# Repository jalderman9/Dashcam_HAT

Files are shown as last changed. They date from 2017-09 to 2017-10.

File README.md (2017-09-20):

# Dashcam HAT

This repository contains the Eagle PCB design files for a board that
attaches to an ASUS Tinkerboard and provides:
 - Regulated 5V power from OBD-II 12V supply
 - Power management via Attiny
 - OBD-II interface (CAN and ISO9141)
 - 3 axis accelerometer
 - magnetometer
 - GPS

PCB top view:

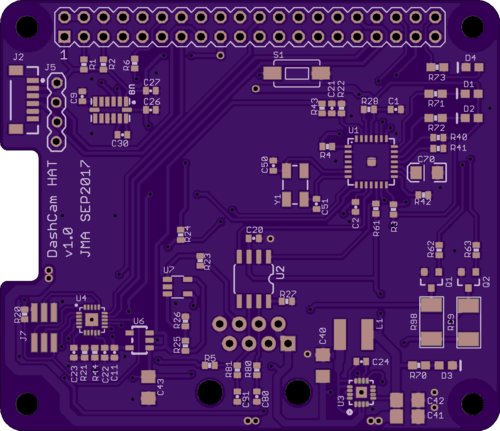
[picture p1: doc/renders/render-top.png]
 

PCB bottom view:

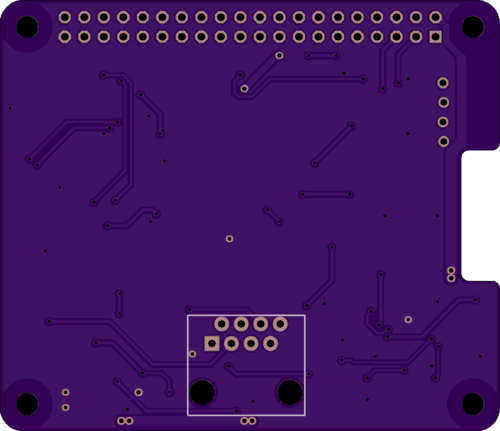
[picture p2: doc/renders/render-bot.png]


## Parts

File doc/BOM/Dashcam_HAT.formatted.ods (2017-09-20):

Qty | Value | Device | Parts | Description | DIGIKEY_PN | MANUFACTURER | MFG_PN
7 | 0.1uF | CAP0402-CAP | C20, C21, C22, C23, C24, C26, C27 | Capacitor | 1276-1001-1-ND | Samsung | CL05B104KO5NNNC
1 | 0.22uF | CAP0402-CAP | C30 | Capacitor | 490-5418-1-ND | Murata | GRM155R71C224KA12D
2 | 27pF | CAP0402-CAP | C50, C51 | Capacitor | 1276-1153-1-ND | Samsung | CL05C270JB5NNNC
3 | 1uF | CAP0402-CAP | C1, C2, C11 | Capacitor | 490-3890-1-ND | Murata | GRM155R61A105KE15D
4 | 10uF | CAP1206 | C40, C41, C42, C43 | Capacitor | 1276-6767-1-ND | Samsung | CL31B106KBHNNNE
1 | 10uF ESR<=5 | CAP_POL1206 | C70 | Capacitor Polarized | 478-8237-1-ND | AVX Corporation | F931C106MAA
1 | 4.7uF | CAP0402-CAP | C9 | Capacitor | 490-5915-1-ND | Murata | GRM155R60J475ME47D
2 | 560pF | CAP0402-CAP | C80, C81 | Capacitor | 1276-1577-1-ND | Samsung | CL05B561KB5NNNC
4 | 1k | RESISTOR0402-RES | R6, R61, R62, R63 | Resistor | 311-1.0KJRCT-ND | Yageo | RC0402JR-071KL
5 | 3.9K | RESISTOR0402-RES | R1, R2, R3, R4, R5 | Resistor | 311-3.9KJRCT-ND | Yageo | RC0402JR-073K9L
9 | 10k | RESISTOR0402-RES | R20, R21, R22, R23, R24, R25, R26, R27, R28 | Resistor | 311-10KJRCT-ND | Yageo | RC0402JR-0710KL
5 | 62K | RESISTOR0402-RES | R40, R41, R42, R43, R44 | Resistor | 311-62.0KLRCT-ND | Yageo | RC0402FR-0762KL
2 | 100 | RESISTOR0402-RES | R80, R81 | Resistor | 311-100JRCT-ND | Yageo | RC0402JR-07100RL
4 | 470 | RESISTOR0603-RES | R70, R71, R72, R73 | Resistor | 311-470JRCT-ND | Yageo | RC0402JR-07470RL
2 | 510 0.5W | R-US_2010 | R98, R99 | Resistor, US Symbol | RHM510BGCT-ND | Rohm Semiconductor | MCR50JZHJ511
1 | 16MHz | CRYSTAL5X3 | Y1 | Crystals | 535-9122-1-ND | Abracon LLC | ABM3B-16.000MHZ-B2-T
1 | BLU | LED0603 | D4 | Surface mount LED | 160-1646-1-ND | Lite-On Inc | LTST-C190TBKT
1 | GRN | LED0603 | D1 | Surface mount LED | 160-1183-1-ND | Lite-On Inc | LTST-C190GKT
1 | ORG | LED0603 | D2 | Surface mount LED | 160-1434-1-ND | Lite-On Inc | LTST-C190KFKT
1 | RED | LED0603 | D3 | Surface mount LED | 160-1436-1-ND | Lite-On Inc | LTST-C190KRKT
1 | ATTINY441/841VQFN20 | ATTINY441/841VQFN20 | U4 | ATtiny441/841 | ATTINY841-MMH-ND | Atmel | ATTINY841-MMH
2 | MMBT2222 | TRANSISTOR_NPNSOT23-3 | Q1, Q2 | Transistor NPN | MMBT2222ALT1GOSCT-ND | ON Semiconductor | MMBT2222ALT1G
1 | NR5040T4R7N | NR5040T4R7N | L1 | Taiyo Yuden Inductor | 587-2373-1-ND | Taiyo Yuden | 587-2373-1-ND
1 | Mom | SWITCH-MOMENTARY-2-SMD-1101NE | S1 |  | P13597SCT-ND | Panasonic | EVQ-PNF04M
1 | STN1110 | SCANTOOL | U1 | STN1110 - Multiprotocol OBD II to UART Interpreter, QFN Package |  | Scantool | STN1110
1 | TL331 | TL331 | U7 | Single differential comparator | 296-10168-1-ND | Texas Instruments | TL331IDBVR
1 | TS30011 | TS30011 | U3 | Semtech High Efficiency 1A/2A/3A Current-Mode | TS30013-M050QFNRCT-ND | Semtech | TS30013-M050QFNR
1 | 3V3 | TC1XXXSOT23-5 | U6 | TC1014/TC1015/TC1185 voltage regulator | AP2204K-3.3TRG1DICT-ND | Diodes Inc | AP2204K-3.3TRG1
1 | LSM303DLHC | LSM303DLHC | U8 | 3-Axis I2C Accelerometer and 3-Axis Magnetometer | 497-11918-1-ND | STMicroelectronics | LSM303DLHCTR
1 | MCP2551 | MCP2551-I/SN | U2 | CAN Driver | MCP2551T-E/SNCT-ND | Microchip Technology | MCP2551T-E/SN
1 | M4 | M4 | J5 | 4 pin 0.1 pitch header
1 | 6_PIN_SMD | 6_PIN_PDISMD | J7 | 6 pin PDI programming header | 609-3693-1-ND | Amphenol FCI | 20021121-00006C4LF
1 | PIN20X2 | PIN20X2 | J3 |  | SAM9315-ND | Samtec Inc | ESQ-120-23-T-D
1 | JST_VERTICAL | JST_VERTICAL | J2 |  | 455-1792-1-ND | JST | BM06B-SRSS-TB(LF)(SN)
1 | RJ45-8PTH | RJ45-8PTH | J1 | RJ45 Jack | 609-1046-ND | Amphenol FCI | 54602-908LF

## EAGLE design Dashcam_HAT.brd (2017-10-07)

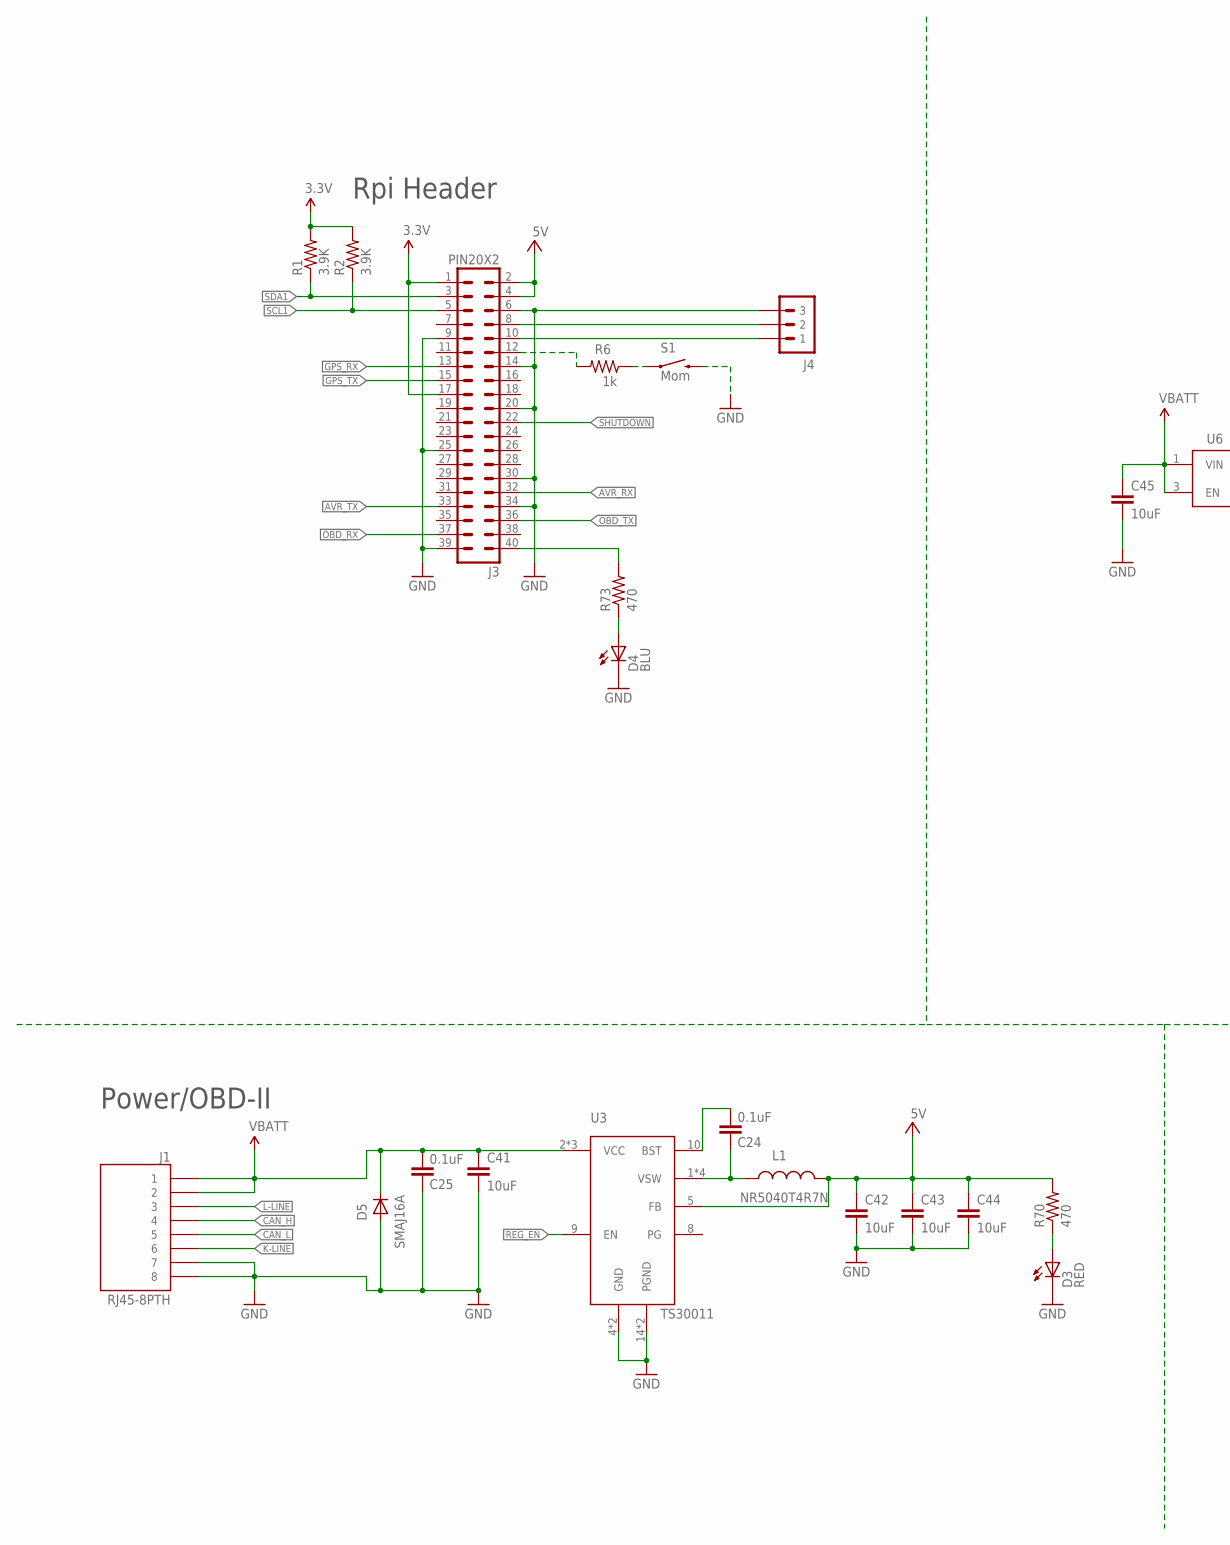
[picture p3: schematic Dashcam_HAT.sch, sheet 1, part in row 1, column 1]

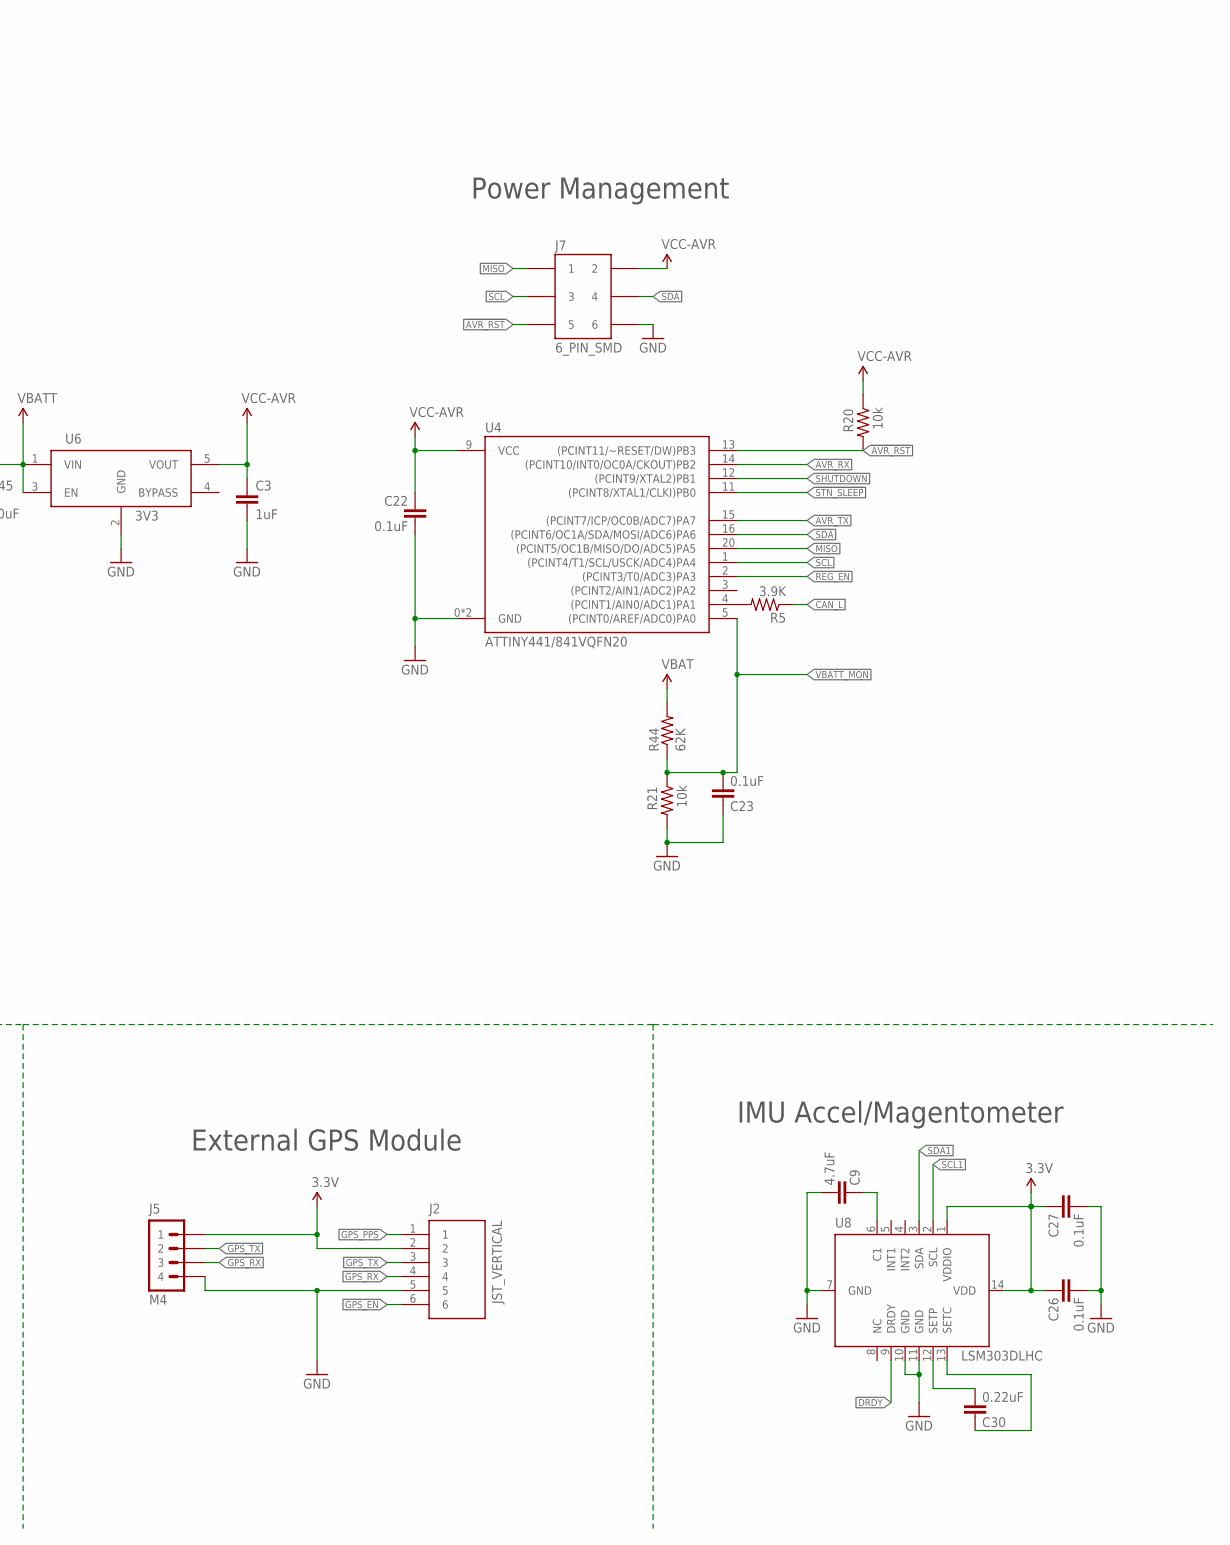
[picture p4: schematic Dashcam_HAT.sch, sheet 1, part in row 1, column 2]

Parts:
C3: 1uF; 0402-CAP; MFG_PN GRM155R61A105KE15D; DIGIKEY_PN 490-3890-1-ND
C9: 4.7uF; 0402-CAP; MFG_PN GRM155R60J475ME47D; DIGIKEY_PN 490-5915-1-ND
C22, C23, C24, C25, C26, C27: 0.1uF; 0402-CAP; MFG_PN CL05B104KO5NNNC; DIGIKEY_PN 1276-1001-1-ND
C30: 0.22uF; 0402-CAP; MFG_PN GRM155R71C224KA12D; DIGIKEY_PN 490-5418-1-ND
C41, C42, C43, C44, C45: 10uF; 1206; MFG_PN CL31B106KBHNNNE; DIGIKEY_PN 1276-6767-1-ND
D3: RED; LED_0603; MFG_PN LTST-C190KRKT; DIGIKEY_PN 160-1436-1-ND
D4: BLU; LED_0603; MFG_PN LTST-C190TBKT; DIGIKEY_PN 160-1646-1-ND
D5: SMAJ16A; SMA; MFG_PN SMAJ16A; DIGIKEY_PN SMAJ16ALFCT-ND
J1: RJ45-8PTH; RJ45-8; MFG_PN 54602-908LF; DIGIKEY_PN 609-1046-ND
J2: JST_VERTICAL; JST-6-SMD-VERT-1.0MM; MFG_PN BM06B-SRSS-TB(LF)(SN); DIGIKEY_PN 455-1792-1-ND
J3: PIN20X2; PIN_20X2; MFG_PN ESQ-120-23-T-D; DIGIKEY_PN SAM9315-ND
J4: M30.1"_LOCK; M3X1_LOCK
J5: M4; M4X1_LOCK
J7: 6_PIN_SMD; M3X2_SMD; MFG_PN 20021121-00006C4LF; DIGIKEY_PN 609-3693-1-ND
L1: NR5040T4R7N; NR5040; MFG_PN 587-2373-1-ND; DIGIKEY_PN 587-2373-1-ND
R1, R2, R5: 3.9K; 0402-RES; MFG_PN RC0402JR-073K9L; DIGIKEY_PN 311-3.9KJRCT-ND
R6: 1k; 0402-RES; MFG_PN RC0402JR-071KL; DIGIKEY_PN 311-1.0KJRCT-ND
R20, R21: 10k; 0402-RES; MFG_PN RC0402JR-0710KL; DIGIKEY_PN 311-10KJRCT-ND
R44: 62K; 0402-RES; MFG_PN RC0402FR-0762KL; DIGIKEY_PN 311-62.0KLRCT-ND
R70, R73: 470; 0603-RES; MFG_PN RC0402JR-07470RL; DIGIKEY_PN 311-470JRCT-ND
S1: Mom; TACTILE-SWITCH-1101NE; MFG_PN EVQ-PNF04M; DIGIKEY_PN P13597SCT-ND
U3: TS30011; QFN-16; MFG_PN TS30013-M050QFNR; DIGIKEY_PN TS30013-M050QFNRCT-ND
U4: ATTINY441/841VQFN20; QFN20_0.45MM; MFG_PN ATTINY841-MMH; DIGIKEY_PN ATTINY841-MMH-ND
U6: 3V3; SOT23-5; MFG_PN AP2204K-3.3TRG1; DIGIKEY_PN AP2204K-3.3TRG1DICT-ND
U8: LSM303DLHC; LGA14; MFG_PN LSM303DLHCTR; DIGIKEY_PN 497-11918-1-ND

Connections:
3.3V: C26.1, C27.1, J2.2, J3.1, J3.17, J5.1, R1.2, R2.2, U8.1 (VDDIO), U8.14 (VDD); also elsewhere on the board
5V: C42.1, C43.1, C44.1, J3.2, J3.4, L1.P$2 (2), R70.2, U3.5 (FB); also elsewhere on the board
!AVR_RST: J7.P$5 (5), R20.2, U4.13 ((PCINT11/~RESET/DW)PB3)
!STN_SLEEP: U4.11 ((PCINT8/XTAL1/CLKI)PB0); also elsewhere on the board
AVR_RX: J3.32, U4.14 ((PCINT10/INT0/OC0A/CKOUT)PB2)
AVR_TX: J3.33, U4.15 ((PCINT7/ICP/OC0B/ADC7)PA7)
BST: C24.2, U3.10 (BST)
CAN_H: J1.4; also elsewhere on the board
CAN_L: J1.5, R5.1; also elsewhere on the board
DRDY: U8.9 (DRDY)
GND: C3.2, C9.2, C22.2, C23.1, C25.1, C26.2, C27.2, C41.2, C42.2, C43.2, C44.2, C45.2, D3.C, D4.C, D5.A, J1.7, J1.8, J2.5, J3.6, J3.9, J3.14, J3.20, J3.25, J3.30, J3.34, J3.39, J4.3, J5.4, J7.P$6 (6), R21.2, S1.P$2 (2), U3.4 (GND), U3.14 (PGND), U3.15 (PGND), U3.EXP (GND), U4.0 (GND), U4.8 (GND), U6.2 (GND), U8.7 (GND), U8.10 (GND), U8.11 (GND); also elsewhere on the board
GPS_EN: J2.6
GPS_PPS: J2.1
GPS_RX: J2.4, J3.13, J5.3
GPS_TX: J2.3, J3.15, J5.2
K-LINE: J1.6; also elsewhere on the board
L-LINE: J1.3; also elsewhere on the board
MISO: J7.P$1 (1), U4.20 ((PCINT5/OC1B/MISO/DO/ADC5)PA5)
unnamed: C9.1, U8.6 (C1)
unnamed: R5.2, U4.4 ((PCINT1/AIN0/ADC1)PA1)
unnamed: D3.A, R70.1
unnamed: D4.A, R73.1
unnamed: C30.2, U8.12 (SETP)
unnamed: C30.1, U8.13 (SETC)
unnamed: J3.12, R6.2
unnamed: R6.1, S1.P$1 (1)
OBD_RX: J3.37; also elsewhere on the board
OBD_TX: J3.36; also elsewhere on the board
REG_EN: U3.9 (EN), U4.2 ((PCINT3/T0/ADC3)PA3)
SCL: J7.P$3 (3), U4.1 ((PCINT4/T1/SCL/USCK/ADC4)PA4)
SCL1: J3.5, R2.1, U8.2 (SCL)
SDA: J7.P$4 (4), U4.16 ((PCINT6/OC1A/SDA/MOSI/ADC6)PA6)
SDA1: J3.3, R1.1, U8.3 (SDA)
SHUTDOWN: J3.22, U4.12 ((PCINT9/XTAL2)PB1)
UART1_RX: J3.10, J4.1
UART1_TX: J3.8, J4.2
USER_LED: J3.40, R73.2
VBATT: C25.2, C41.1, C45.1, D5.K (C), J1.1, J1.2, R44.2, U3.2 (VCC), U3.3 (VCC), U3.11 (VCC), U6.1 (VIN), U6.3 (EN); also elsewhere on the board
VBATT_MON: C23.2, R21.1, R44.1, U4.5 ((PCINT0/AREF/ADC0)PA0)
VCC-AVR: C3.1, C22.1, J7.P$2 (2), R20.1, U4.9 (VCC), U6.5 (VOUT)
VSW: C24.1, L1.P$1 (1), U3.1 (VSW), U3.12 (VSW), U3.13 (VSW), U3.16 (VSW)

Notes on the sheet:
External GPS Module
Rpi Header
IMU Accel/Magentometer
Power/OBD-II
Power Management

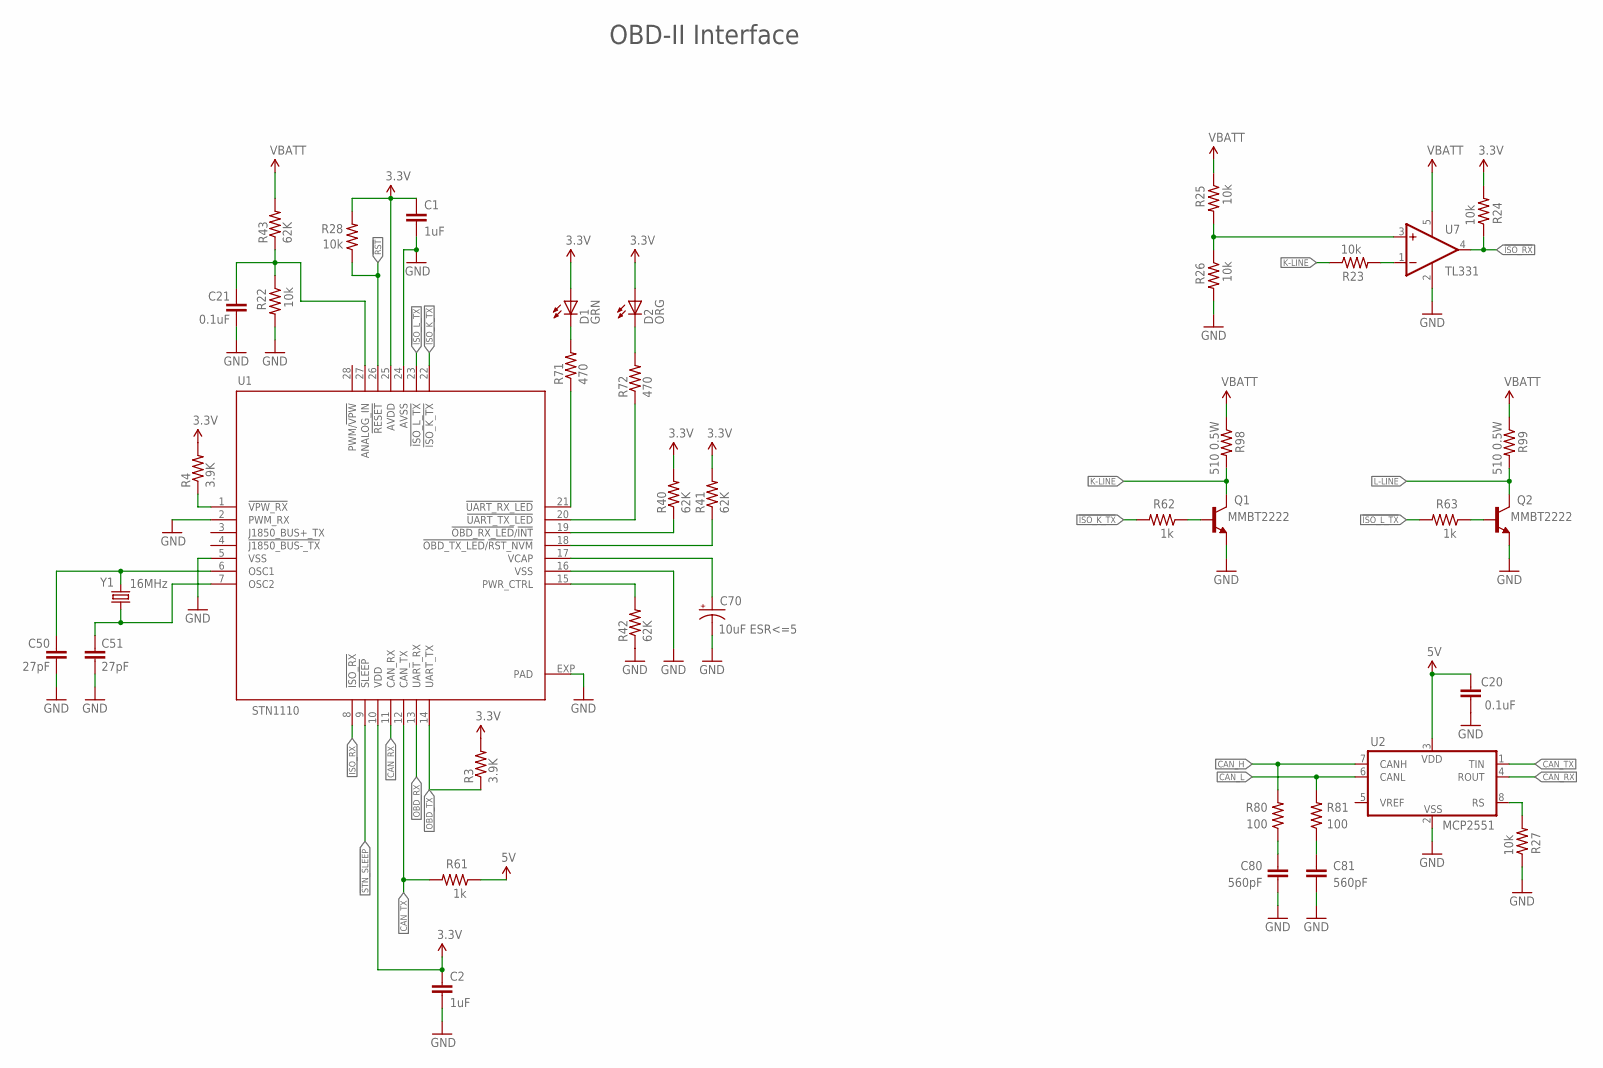
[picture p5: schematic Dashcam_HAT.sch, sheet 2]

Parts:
C1, C2: 1uF; 0402-CAP; MFG_PN GRM155R61A105KE15D; DIGIKEY_PN 490-3890-1-ND
C20, C21: 0.1uF; 0402-CAP; MFG_PN CL05B104KO5NNNC; DIGIKEY_PN 1276-1001-1-ND
C50: 27pF; 0402-CAP; MFG_PN CL05C270JB5NNNC; DIGIKEY_PN 1276-1153-1-ND
C51: 27pF; 0402-CAP
C70: 10uF ESR<=5; EIA3216; MFG_PN F931C106MAA; DIGIKEY_PN 478-8237-1-ND
C80, C81: 560pF; 0402-CAP; MFG_PN CL05B561KB5NNNC; DIGIKEY_PN 1276-1577-1-ND
D1: GRN; LED_0603; MFG_PN LTST-C190GKT; DIGIKEY_PN 160-1183-1-ND
D2: ORG; LED_0603; MFG_PN LTST-C190KFKT; DIGIKEY_PN 160-1434-1-ND
Q1, Q2: MMBT2222; SOT23-3; MFG_PN MMBT2222ALT1G; DIGIKEY_PN MMBT2222ALT1GOSCT-ND
R3, R4: 3.9K; 0402-RES; MFG_PN RC0402JR-073K9L; DIGIKEY_PN 311-3.9KJRCT-ND
R22, R23, R24, R25, R26, R27: 10k; 0402-RES; MFG_PN RC0402JR-0710KL; DIGIKEY_PN 311-10KJRCT-ND
R28: 10k; 0402-RES
R40, R41, R42, R43: 62K; 0402-RES; MFG_PN RC0402FR-0762KL; DIGIKEY_PN 311-62.0KLRCT-ND
R61, R62, R63: 1k; 0402-RES; MFG_PN RC0402JR-071KL; DIGIKEY_PN 311-1.0KJRCT-ND
R71, R72: 470; 0603-RES; MFG_PN RC0402JR-07470RL; DIGIKEY_PN 311-470JRCT-ND
R80, R81: 100; 0402-RES; MFG_PN RC0402JR-07100RL; DIGIKEY_PN 311-100JRCT-ND
R98, R99: 510 0.5W; 2010; MFG_PN MCR50JZHJ511; DIGIKEY_PN RHM510BGCT-ND
U1: STN1110; _STN_SCANTOOL_QFN-28-S
U2: MCP2551; SO-8; MFG_PN MCP2551T-E/SN; DIGIKEY_PN MCP2551T-E/SNCT-ND
U7: TL331; DBV-R-PDSO-G5; MFG_PN TL331IDBVR; DIGIKEY_PN 296-10168-1-ND
Y1: 16MHz; CRYSTAL-SMD-5X3; MFG_PN ABM3B-16.000MHZ-B2-T; DIGIKEY_PN 535-9122-1-ND

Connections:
3.3V: C1.1, C2.1, D1.A, D2.A, R3.2, R4.2, R24.2, R28.2, R40.2, R41.2, U1.10 (VDD), U1.25 (AVDD); also elsewhere on the board
5V: C20.1, R61.1, U2.3 (VDD); also elsewhere on the board
!ISO_K_TX: R62.2, U1.22 (!ISO_K_TX)
!ISO_L_TX: R63.2, U1.23 (!ISO_L_TX)
!ISO_RX: R24.1, U1.8 (!ISO_RX), U7.4 (OUT)
!RST: R28.1, U1.26 (!RESET)
!STN_SLEEP: U1.9 (!SLEEP); also elsewhere on the board
BATT_V: C21.1, R22.1, R43.1, U1.27 (ANALOG_IN)
CAN_H: R80.2, U2.7 (CANH); also elsewhere on the board
CAN_L: R81.2, U2.6 (CANL); also elsewhere on the board
CAN_RX: U1.11 (CAN_RX), U2.4 (ROUT)
CAN_TX: R61.2, U1.12 (CAN_TX), U2.1 (TIN)
GND: C1.2, C2.2, C20.2, C21.2, C50.2, C51.2, C70.C (-), C80.2, C81.2, Q1.2 (E), Q2.2 (E), R22.2, R26.2, R27.1, R42.1, U1.2 (PWM_RX), U1.5 (VSS), U1.16 (VSS), U1.24 (AVSS), U1.EXP (PAD), U2.2 (VSS), U7.2 (GND); also elsewhere on the board
K-LINE: Q1.3 (C), R23.1, R98.2; also elsewhere on the board
L-LINE: Q2.3 (C), R99.2; also elsewhere on the board
unnamed: R71.1, U1.21 (!UART_RX_LED)
unnamed: Q1.1 (B), R62.1
unnamed: Q2.1 (B), R63.1
unnamed: R25.2, R26.1, U7.3 (+IN)
unnamed: R72.1, U1.20 (!UART_TX_LED)
unnamed: R42.2, U1.15 (PWR_CTRL)
unnamed: R4.1, U1.1 (!VPW_RX)
unnamed: C80.1, R80.1
unnamed: R27.2, U2.8 (RS)
unnamed: R23.2, U7.1 (-IN)
unnamed: R41.1, U1.18 (!OBD_TX_LED!/!RST_NVM)
unnamed: R40.1, U1.19 (!OBD_RX_LED!/!INT)
unnamed: C70.A (+), U1.17 (VCAP)
unnamed: C81.1, R81.1
unnamed: D1.C, R71.2
unnamed: D2.C, R72.2
OBD_RX: U1.13 (UART_RX); also elsewhere on the board
OBD_TX: R3.1, U1.14 (UART_TX); also elsewhere on the board
OSC1: C50.1, U1.6 (OSC1), Y1.3 (2)
OSC2: C51.1, U1.7 (OSC2), Y1.1
VBATT: R25.1, R43.2, R98.1, R99.1, U7.5 (V+); also elsewhere on the board

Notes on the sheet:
OBD-II Interface

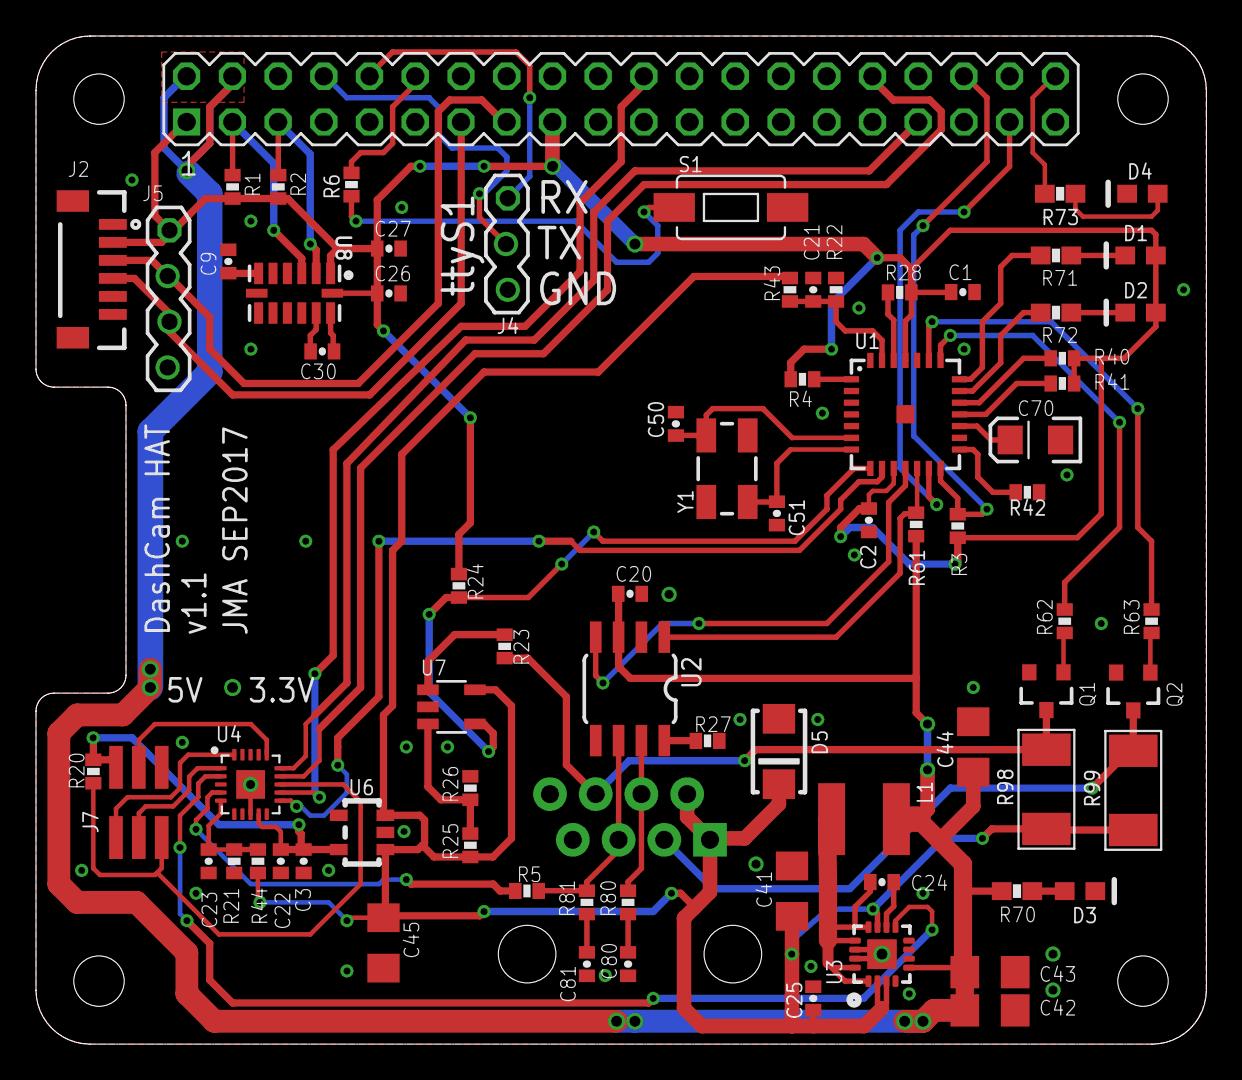
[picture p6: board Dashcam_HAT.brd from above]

Board: 2 copper layers, 65.0 x 56.0 mm, 77 parts (1 on the bottom side), 63 nets.

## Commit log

2017-09-20 Added missing attributes for TL331 comparator
    [Dashcam_HAT.brd, Dashcam_HAT.sch]
2017-09-20 Added Bill of Materials
    [Dashcam_HAT.formatted.ods]
2017-09-20 Reformatted BOM
    [Dashcam_HAT.formatted.ods]
2017-09-30 Updated part identifiers
    [Dashcam_HAT.brd, Dashcam_HAT.sch]
2017-09-30 Tweaked layout a bit and added more bypass caps
    [Dashcam_HAT.brd, Dashcam_HAT.sch]
2017-10-07 tweaked layout
    [Dashcam_HAT.brd]

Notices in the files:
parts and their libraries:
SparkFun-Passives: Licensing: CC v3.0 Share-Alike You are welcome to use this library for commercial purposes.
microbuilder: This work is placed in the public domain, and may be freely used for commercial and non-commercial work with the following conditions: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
